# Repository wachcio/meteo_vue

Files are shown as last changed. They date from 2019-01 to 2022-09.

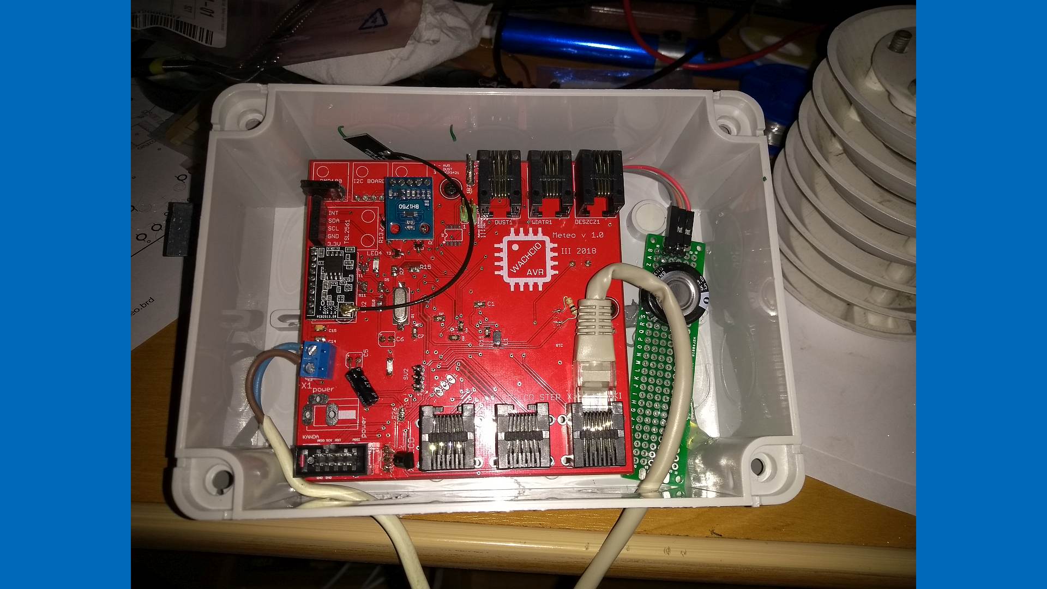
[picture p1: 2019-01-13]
src/assets/slider/IMG_20180407_161515269.jpg

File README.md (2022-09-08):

# meteo_vue
System zbierania danych z kilkudziesięciu czujników. Zaczął powstawać w maju 2016 roku. Strona typu SPA powstaje od grudnia 2018 przy pomocy framework-a Vue.

Od jakiegoś czasu działał u mnie minikomputer Raspberry Pi z zainstalowanym Raspianem oraz systemem monitoringu temperatury (i nie tylko) Nettemp autorstwa techfreak. Mierzy on temperatury w kotłowni i na zewnątrz budynku za pomocą czujników DS18B20 oraz DHT22 (bardzo słabe i zawodne).

Po kilku miesiącach zacząłem myśleć nad własną stacją pogody która mogła by oprócz temperatur mierzyłć również inne parametry i co najważniejsze była mojego autorstwa. Dzięki pomocy ze strony forum Atnel oraz kanałowi YouTube Atnel - mirekk36 zaprojektowałem a następnie polutowałem urządzenie i zaprogramowałem w języku C mikrokontroler Atmega 32A który jest sercem stacji meteo. Stacja zbiera informacje z czujników: temperatury (DS18B20, BMP180, SHT21), wilgotności (SHT21), ciśnienia (BMP180), wiatru, opadów oraz nasłonecznienia (BH1750). 9 lutego 2020 zamieniłem czujnki SHT21 i BMP 180 na jeden BME280 który mierzy temperaturę, ciśnienie i wilgotność.

Zachęcony udaną budową stacji złożyłem projekt firmy Atnel opisany w żółtej książce Mirosława Kardasia czyli zegar w dwóch sztukach. Po modyfikacjach oprogramowania zegary znajdujące się w salonie oraz sypialni wysyłają dane do Raspberry Pi który zapisuje je w zewnętrznej bazie danych.

Kolejną małą częścią projektu stało się urządzenie oparte o znany moduł wi-fi ESP8266 do którego podłączyłem czujnik temperatury DS18B20 w hermetcznej obudowie i umieściłem w akwarium. On również wysyła swoje dane do Nettemp-a.

Ostatnim elementem układanki jest odpytywanie bazy danych Airly o dane z czujników jakości powietrza znajdującego się w mojej miejscowości (od maja 2021 dostępne są dwa czujniki).

Dane z wszystkich moich części systemu trafiają co minutę (dane jakości powietrza ze względu na ograniczenia AirlyAPI odczytywane są co kwadrans) do bazy danych MySQL umieszczonej na zewnętrznym serwerze. Odbywa się to za pośrednictwem napisanych przeze mnie skryptów PHP. Dopiero z tej bazy poprzez mój mini system Rest API czerpie informacje ta strona. Jeśli jest problem z danym czujnikiem i z jakiegoś powodu dane są starsze niż 5 minut (16 minut czujniki jakości powietrza) sygnalizowane to jest czerwoną obwódką wokół ikony czujnika. Po kliknięciu na czujnik pokazują się bardziej szczegółowe informacje. Natomist kliknięcie na tytuł kategorii powoduje jej ukrycie lub pokazanie.

## Demo
http://meteo.wachcio.pl/

## Project setup
```
npm install
```

### Compiles and hot-reloads for development
```
npm run serve
```

### Compiles and minifies for production
```
npm run build
```

### Run your tests
```
npm run test
```

### Lints and fixes files
```
npm run lint
```

### Customize configuration
See [Configuration Reference](https://cli.vuejs.org/config/).

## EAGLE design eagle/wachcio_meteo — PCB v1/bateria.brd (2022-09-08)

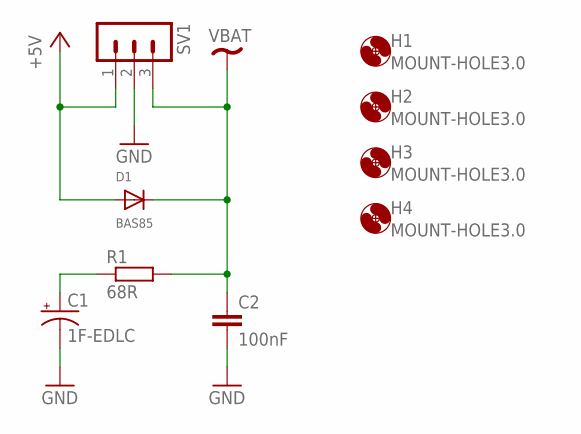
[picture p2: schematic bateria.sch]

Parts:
C1: 1F-EDLC; CAP-RADIAL-5MM-21.5MM
C2: 100nF; C0805
D1: BAS85; SMADIODE
H1, H2, H3, H4: MOUNT-HOLE3.0; 3,0
R1: 68R; R0805
SV1: MA03-1

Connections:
+5V: D1.A, SV1.1
GND: C1.-, C2.2, SV1.2
unnamed: C1.+, R1.1
VBAT: C2.1, D1.C, R1.2, SV1.3

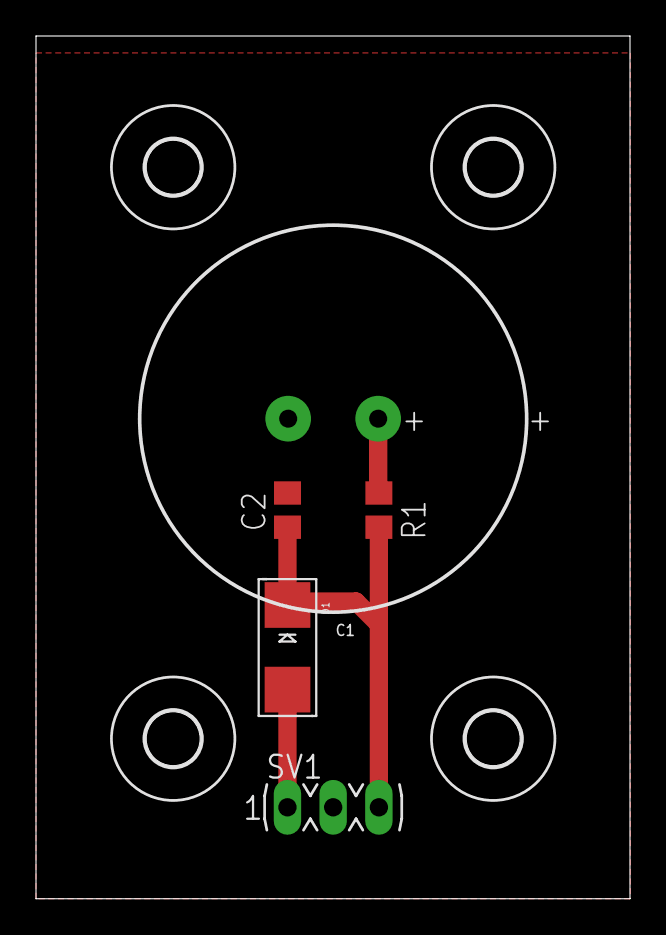
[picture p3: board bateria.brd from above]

Board: 2 copper layers, 33.0 x 47.9 mm, 9 parts (0 on the bottom side), 4 nets.

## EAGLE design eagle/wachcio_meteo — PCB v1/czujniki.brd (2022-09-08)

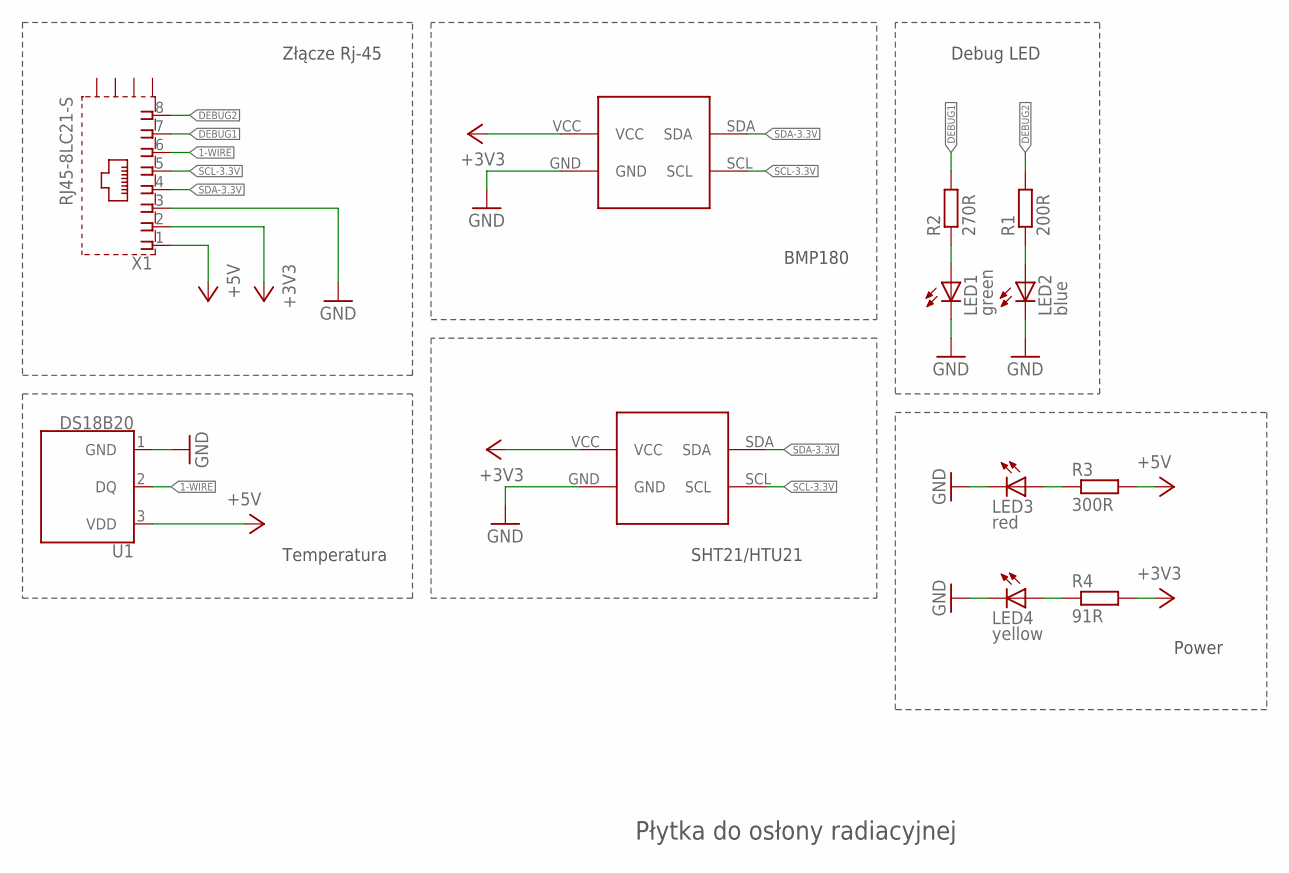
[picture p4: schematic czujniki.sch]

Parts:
LED1: green; CHIPLED_1206
LED2: blue; CHIPLED_1206
LED3: red; CHIPLED_1206
LED4: yellow; CHIPLED_1206
R1: 200R; M0805
R2: 270R; M0805
R3: 300R; M0805
R4: 91R; M0805
U1: DS18B20; TO-92-AMMO
U$1: BMP180
U$2: I2C_BOARD
X1: RJ45-8LC21-S; RJ45-SHIELD1

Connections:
1-WIRE: U1.2 (DQ), X1.6
+3V3: R4.2, U$1.VCC, U$2.VCC, X1.2
+5V: R3.2, U1.3 (VDD), X1.1
DEBUG1: R2.2, X1.7
DEBUG2: R1.2, X1.8
GND: LED1.C, LED2.C, LED3.C, LED4.C, U1.1 (GND), U$1.GND, U$2.GND, X1.3
unnamed: LED1.A, R2.1
unnamed: LED2.A, R1.1
unnamed: LED3.A, R3.1
unnamed: LED4.A, R4.1
SCL-3.3V: U$1.SCL, U$2.SCL, X1.5
SDA-3.3V: U$1.SDA, U$2.SDA, X1.4

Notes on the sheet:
BMP180
SHT21/HTU21
Złącze Rj-45
Temperatura
Debug LED
Płytka do osłony radiacyjnej
Power

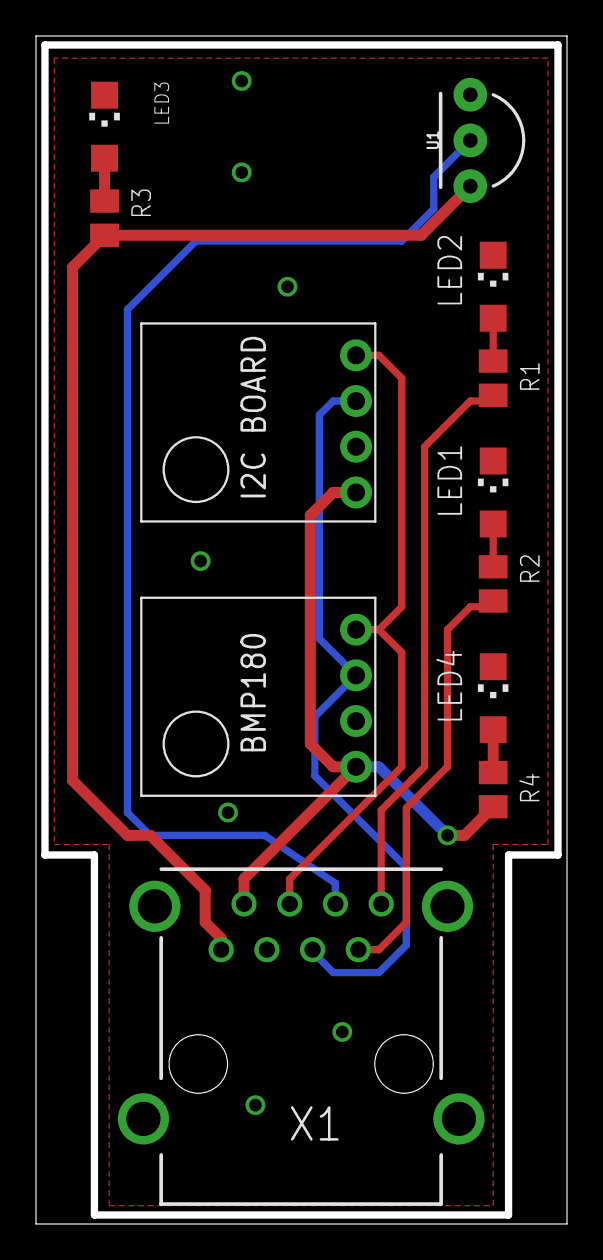
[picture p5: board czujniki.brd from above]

Board: 2 copper layers, 29.5 x 66.0 mm, 12 parts (0 on the bottom side), 12 nets.

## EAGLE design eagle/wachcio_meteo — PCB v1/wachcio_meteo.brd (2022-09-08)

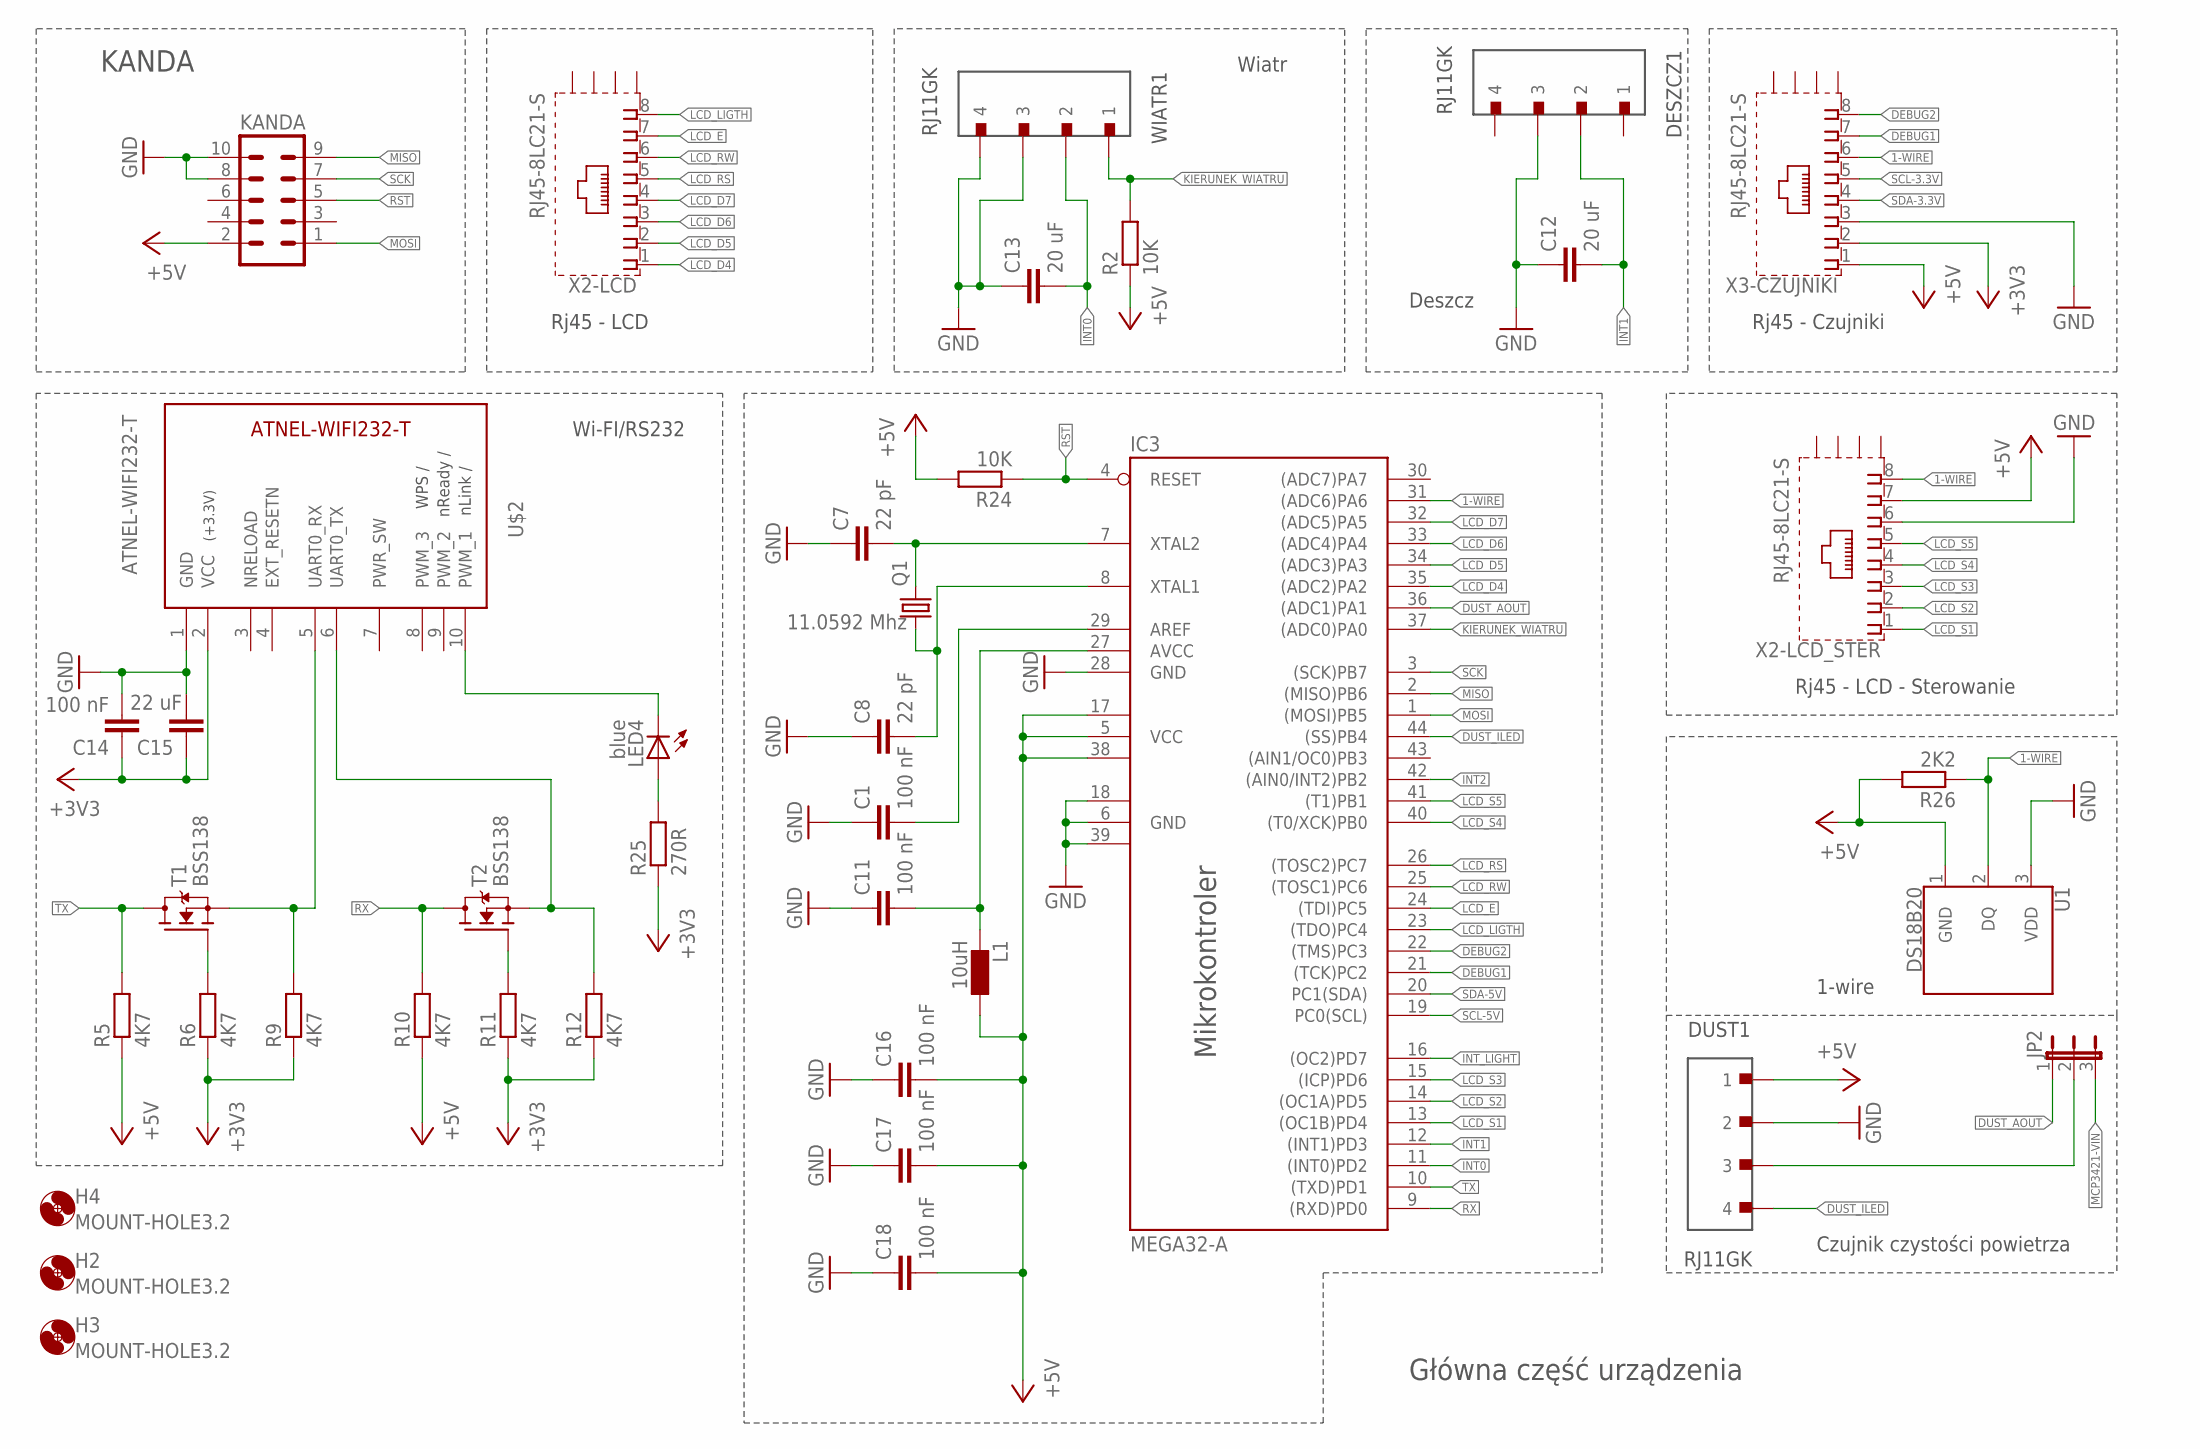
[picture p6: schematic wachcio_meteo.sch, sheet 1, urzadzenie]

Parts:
C1, C11, C14, C16, C17, C18: 100 nF; C0805
C7, C8: 22 pF; C0805
C12, C13: 20 uF; C0805
C15: 22 uF; C0805
DESZCZ1: RJ11GK
DUST1: RJ11GK
H2, H3, H4: MOUNT-HOLE3.2; 3,2
IC3: MEGA32-A; TQFP44
JP2: JP2E; JP2
KANDA: ML10
L1: 10uH; L3230M
LED4: blue; CHIPLED_1206
Q1: 11.0592 Mhz; SM49
R2, R24: 10K; M0805
R5, R6, R9, R10, R11, R12: 4K7; M0805
R25: 270R; M0805
R26: 2K2; M0805
T1, T2: BSS138; SOT23
U1: DS18B20; TO-92-AMMO
U$2: ATNEL-WIFI232-T
WIATR1: RJ11GK
X2-LCD, X2-LCD_STER, X3-CZUJNIKI: RJ45-8LC21-S; RJ45-SHIELD1

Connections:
1-WIRE: IC3.31 ((ADC6)PA6), R26.1, U1.2 (DQ), X2-LCD_STER.8, X3-CZUJNIKI.6
+3V3: C14.1, C15.1, R6.1, R9.1, R11.1, R12.1, R25.1, U$2.2 (VCC), X3-CZUJNIKI.2; also elsewhere on the board
+5V: C16.2, C17.2, C18.2, DUST1.1, IC3.5 (VCC), IC3.17 (VCC1), IC3.38 (VCC2), KANDA.2, L1.1, R2.1, R5.1, R10.1, R24.2, R26.2, U1.1 (GND), X2-LCD_STER.7, X3-CZUJNIKI.1; also elsewhere on the board
DEBUG1: IC3.21 ((TCK)PC2), X3-CZUJNIKI.7
DEBUG2: IC3.22 ((TMS)PC3), X3-CZUJNIKI.8
DUST_AOUT: IC3.36 ((ADC1)PA1), JP2.1
DUST_ILED: DUST1.4, IC3.44 ((SS)PB4)
GND: C1.1, C7.1, C8.1, C11.1, C12.1, C13.1, C14.2, C15.2, C16.1, C17.1, C18.1, DESZCZ1.3, DUST1.2, IC3.6 (GND), IC3.18 (GND1), IC3.28 (GND), IC3.39 (GND2), KANDA.8, KANDA.10, U1.3 (VDD), U$2.1 (GND), WIATR1.3, WIATR1.4, X2-LCD_STER.6, X3-CZUJNIKI.3; also elsewhere on the board
INT0: C13.2, IC3.11 ((INT0)PD2), WIATR1.2
INT1: C12.2, DESZCZ1.2, IC3.12 ((INT1)PD3)
INT2: IC3.42 ((AIN0/INT2)PB2); also elsewhere on the board
INT_LIGHT: IC3.16 ((OC2)PD7); also elsewhere on the board
KIERUNEK_WIATRU: IC3.37 ((ADC0)PA0), R2.2, WIATR1.1
LCD_D4: IC3.35 ((ADC2)PA2), X2-LCD.1
LCD_D5: IC3.34 ((ADC3)PA3), X2-LCD.2
LCD_D6: IC3.33 ((ADC4)PA4), X2-LCD.3
LCD_D7: IC3.32 ((ADC5)PA5), X2-LCD.4
LCD_E: IC3.24 ((TDI)PC5), X2-LCD.7
LCD_LIGTH: IC3.23 ((TDO)PC4), X2-LCD.8
LCD_RS: IC3.26 ((TOSC2)PC7), X2-LCD.5
LCD_RW: IC3.25 ((TOSC1)PC6), X2-LCD.6
LCD_S1: IC3.13 ((OC1B)PD4), X2-LCD_STER.1
LCD_S2: IC3.14 ((OC1A)PD5), X2-LCD_STER.2
LCD_S3: IC3.15 ((ICP)PD6), X2-LCD_STER.3
LCD_S4: IC3.40 ((T0/XCK)PB0), X2-LCD_STER.4
LCD_S5: IC3.41 ((T1)PB1), X2-LCD_STER.5
MCP3421-VIN: JP2.3; also elsewhere on the board
MISO: IC3.2 ((MISO)PB6), KANDA.9
MOSI: IC3.1 ((MOSI)PB5), KANDA.1
unnamed: R9.2, T1.2 (S), U$2.5 (UART0_RX)
unnamed: C11.2, IC3.27 (AVCC), L1.2
unnamed: C1.2, IC3.29 (AREF)
unnamed: LED4.A, R25.2
unnamed: R6.2, T1.1 (G)
unnamed: LED4.C, U$2.10 (PWM_1)
unnamed: R12.2, T2.2 (S), U$2.6 (UART0_TX)
unnamed: C7.2, IC3.7 (XTAL2), Q1.2
unnamed: C8.2, IC3.8 (XTAL1), Q1.1
unnamed: DUST1.3, JP2.2
unnamed: R11.2, T2.1 (G)
RST: IC3.4 (RESET), KANDA.5, R24.1
RX: IC3.9 ((RXD)PD0), R10.2, T2.3 (D)
SCK: IC3.3 ((SCK)PB7), KANDA.7
SCL-3.3V: X3-CZUJNIKI.5; also elsewhere on the board
SCL-5V: IC3.19 (PC0(SCL)); also elsewhere on the board
SDA-3.3V: X3-CZUJNIKI.4; also elsewhere on the board
SDA-5V: IC3.20 (PC1(SDA)); also elsewhere on the board
TX: IC3.10 ((TXD)PD1), R5.2, T1.3 (D)

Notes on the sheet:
KANDA
Mikrokontroler
Rj45 - LCD
Wiatr
Deszcz
Rj45 - Czujniki
Wi-FI/RS232
1-wire
Rj45 - LCD - Sterowanie
Główna część urządzenia
Czujnik czystości powietrza

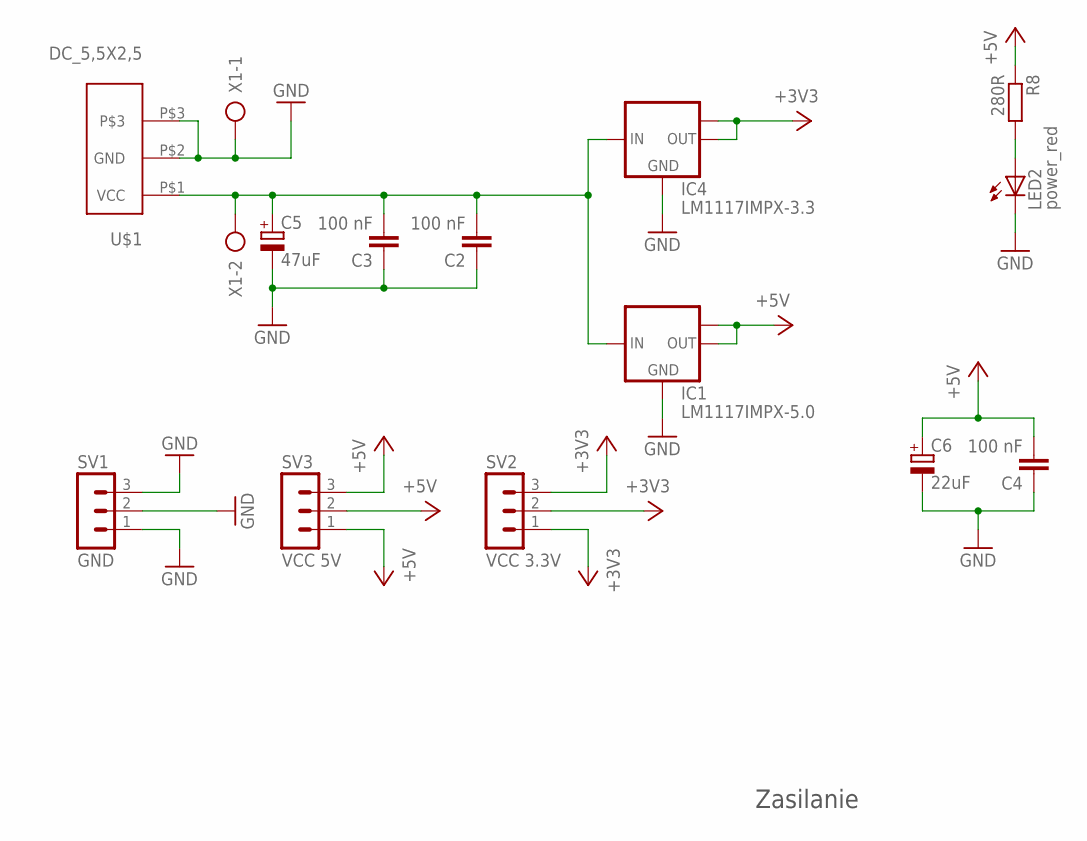
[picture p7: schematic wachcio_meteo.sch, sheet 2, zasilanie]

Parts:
C2, C3, C4: 100 nF; C0805
C5: 47uF; B45181A
C6: 22uF; B45181A
IC1: LM1117IMPX-5.0; SOT223
IC4: LM1117IMPX-3.3; SOT223
LED2: power_red; CHIPLED_1206
R8: 280R; M0805
SV1: GND; MA03-1
SV2: VCC 3.3V; MA03-1
SV3: VCC 5V; MA03-1
U$1: DC_5,5X2,5
X1: AK500/2

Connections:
+3V3: IC4.2 (OUT), IC4.TAB (OUT1), SV2.1, SV2.2, SV2.3; also elsewhere on the board
+5V: C4.2, C6.+, IC1.2 (OUT), IC1.TAB (OUT1), R8.1, SV3.1, SV3.2, SV3.3; also elsewhere on the board
+9V: C2.2, C3.2, C5.+, IC1.3 (IN), IC4.3 (IN), U$1.P$1 (VCC), X1.2
GND: C2.1, C3.1, C4.1, C5.-, C6.-, IC1.1 (GND), IC4.1 (GND), LED2.C, SV1.1, SV1.2, SV1.3, U$1.P$2 (GND), U$1.P$3, X1.1; also elsewhere on the board
unnamed: LED2.A, R8.2

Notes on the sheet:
Zasilanie

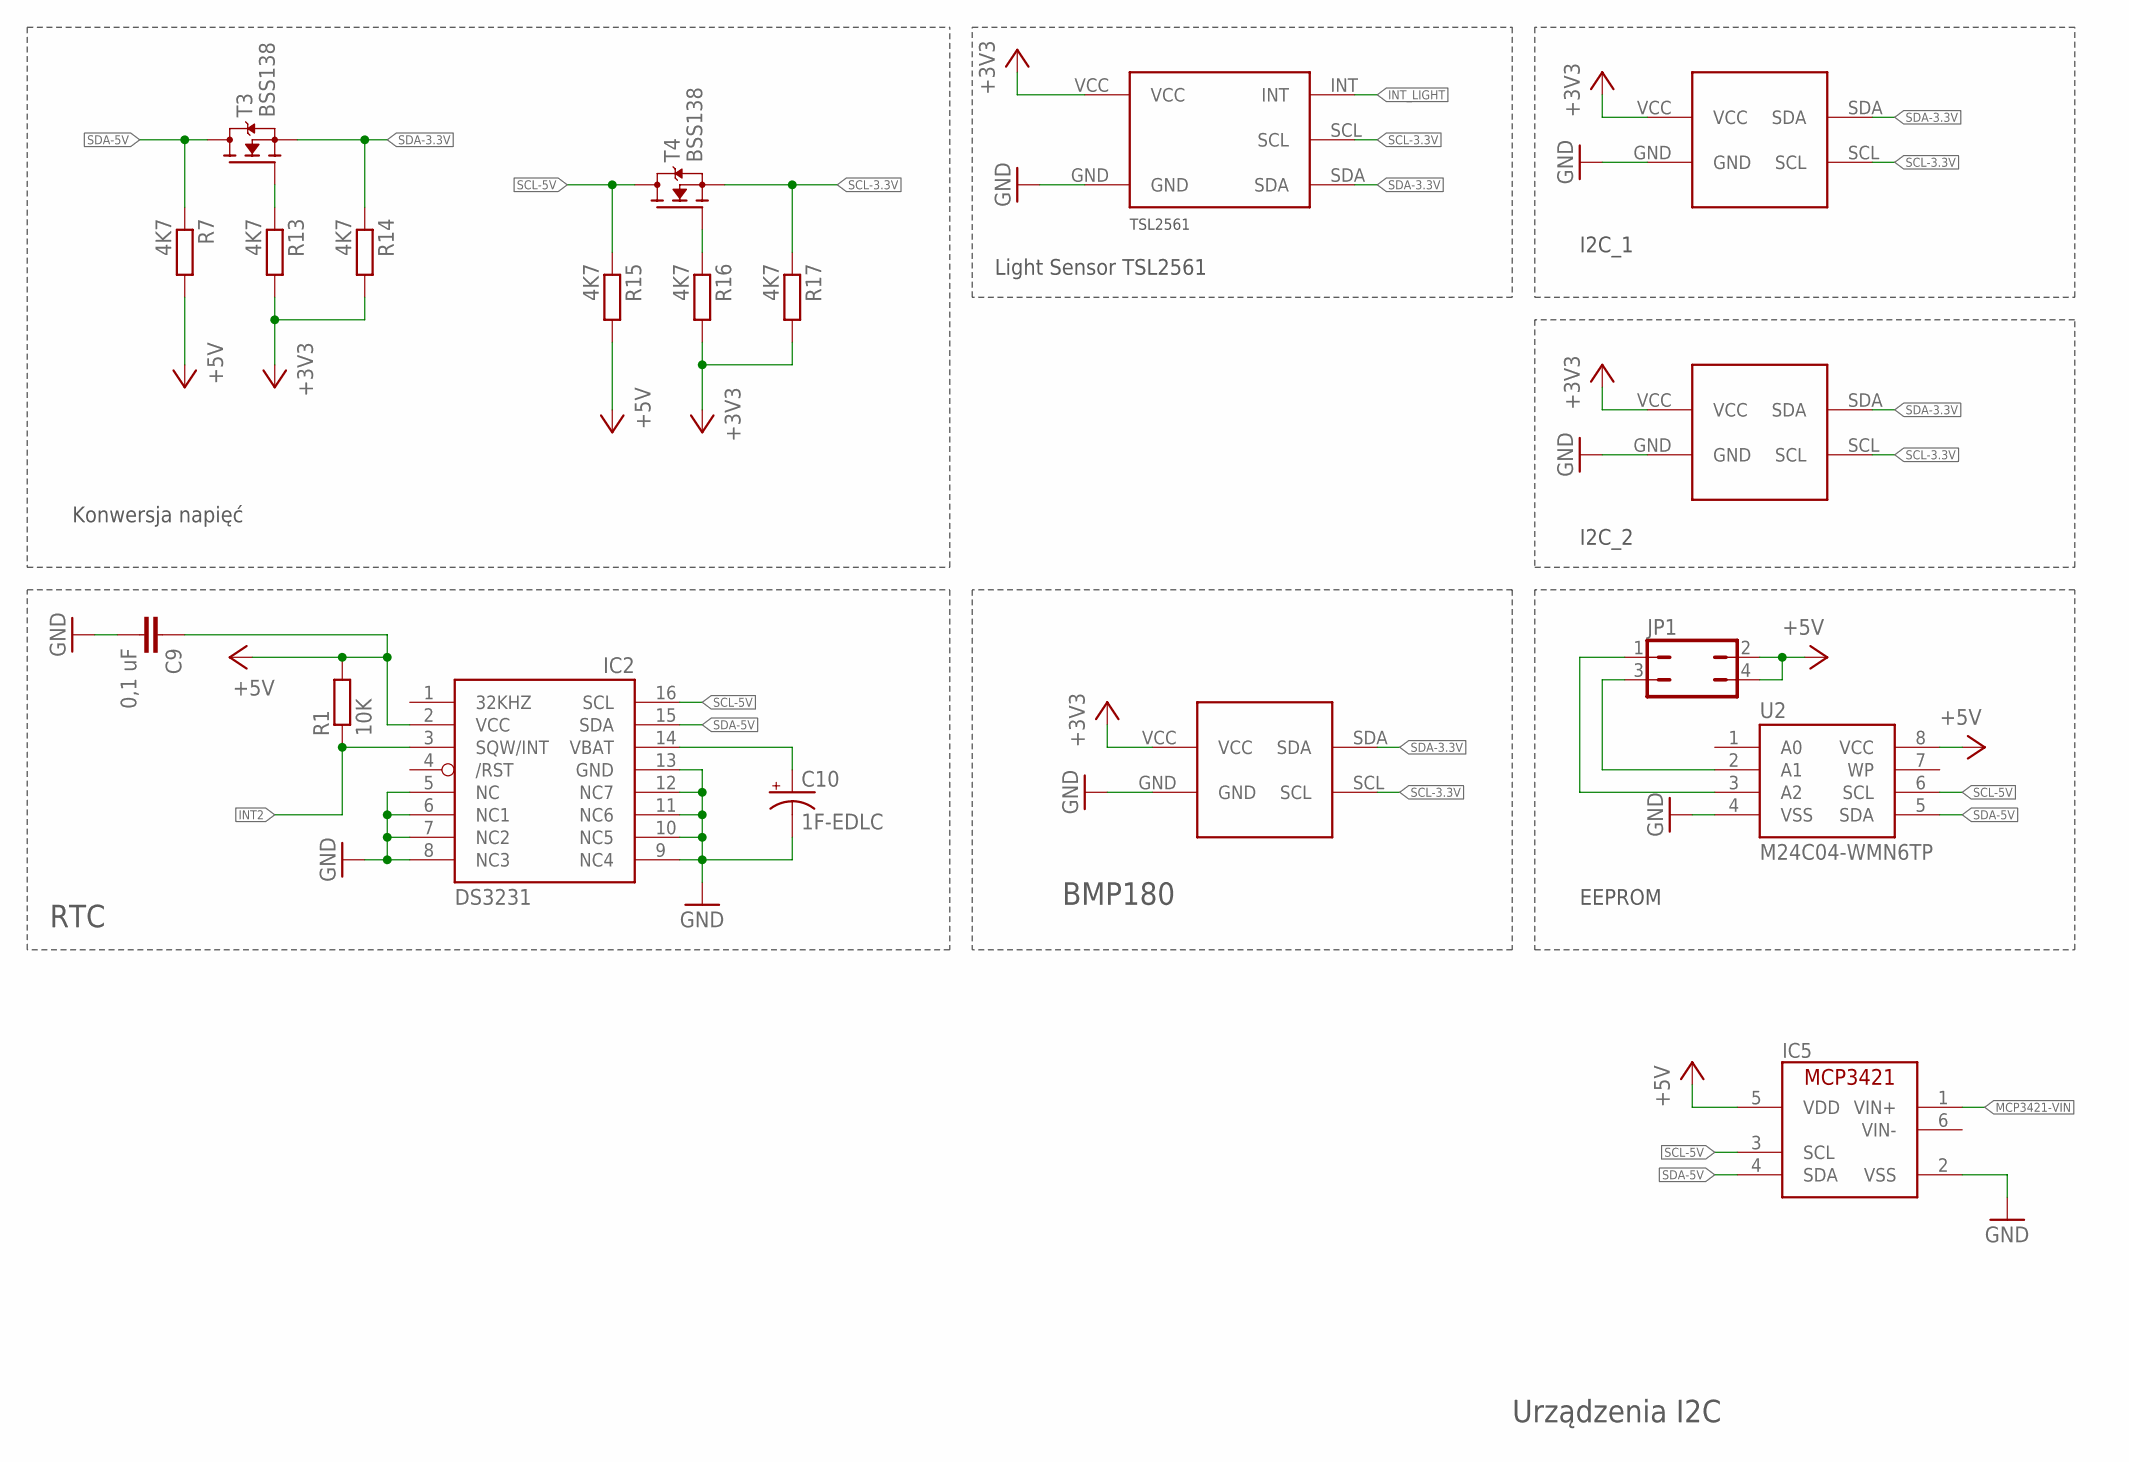
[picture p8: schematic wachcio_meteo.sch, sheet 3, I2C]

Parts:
C9: 0,1 uF; C0805
C10: 1F-EDLC; CAP-RADIAL-5MM-21.5MM
IC2: DS3231/SO; SO16W
IC5: MCP3421; SOT-23
JP1: JP2Q
R1: 10K; M0805
R7, R13, R14, R15, R16, R17: 4K7; M0805
T3, T4: BSS138; SOT23
U2: M24C04-WMN6TP; SO08
U$3: BMP180
U$5, U$6: I2C_BOARD
U$7: TSL2561GY-2561; TSL2561

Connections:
+3V3: R13.2, R14.2, R16.2, R17.2, U$3.VCC, U$5.VCC, U$6.VCC, U$7.VCC; also elsewhere on the board
+5V: C9.1, IC2.2 (VCC), IC5.5 (VDD), JP1.2, JP1.4, R1.2, R7.2, R15.2, U2.8 (VCC); also elsewhere on the board
GND: C9.2, C10.-, IC2.5 (NC), IC2.6 (NC1), IC2.7 (NC2), IC2.8 (NC3), IC2.9 (NC4), IC2.10 (NC5), IC2.11 (NC6), IC2.12 (NC7), IC2.13 (GND), IC5.2 (VSS), U2.4 (VSS), U$3.GND, U$5.GND, U$6.GND, U$7.GND; also elsewhere on the board
INT2: IC2.3 (SQW/INT), R1.1; also elsewhere on the board
INT_LIGHT: U$7.INT; also elsewhere on the board
MCP3421-VIN: IC5.1 (VIN+); also elsewhere on the board
unnamed: C10.+, IC2.14 (VBAT)
unnamed: R13.1, T3.1 (G)
unnamed: R16.1, T4.1 (G)
unnamed: JP1.3, U2.2 (A1)
unnamed: JP1.1, U2.3 (A2)
SCL-3.3V: R17.1, T4.2 (S), U$3.SCL, U$5.SCL, U$6.SCL, U$7.SCL; also elsewhere on the board
SCL-5V: IC2.16 (SCL), IC5.3 (SCL), R15.1, T4.3 (D), U2.6 (SCL); also elsewhere on the board
SDA-3.3V: R14.1, T3.2 (S), U$3.SDA, U$5.SDA, U$6.SDA, U$7.SDA; also elsewhere on the board
SDA-5V: IC2.15 (SDA), IC5.4 (SDA), R7.1, T3.3 (D), U2.5 (SDA); also elsewhere on the board

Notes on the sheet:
Konwersja napięć
RTC
BMP180
I2C_1
I2C_2
EEPROM
Light Sensor TSL2561
Urządzenia I2C

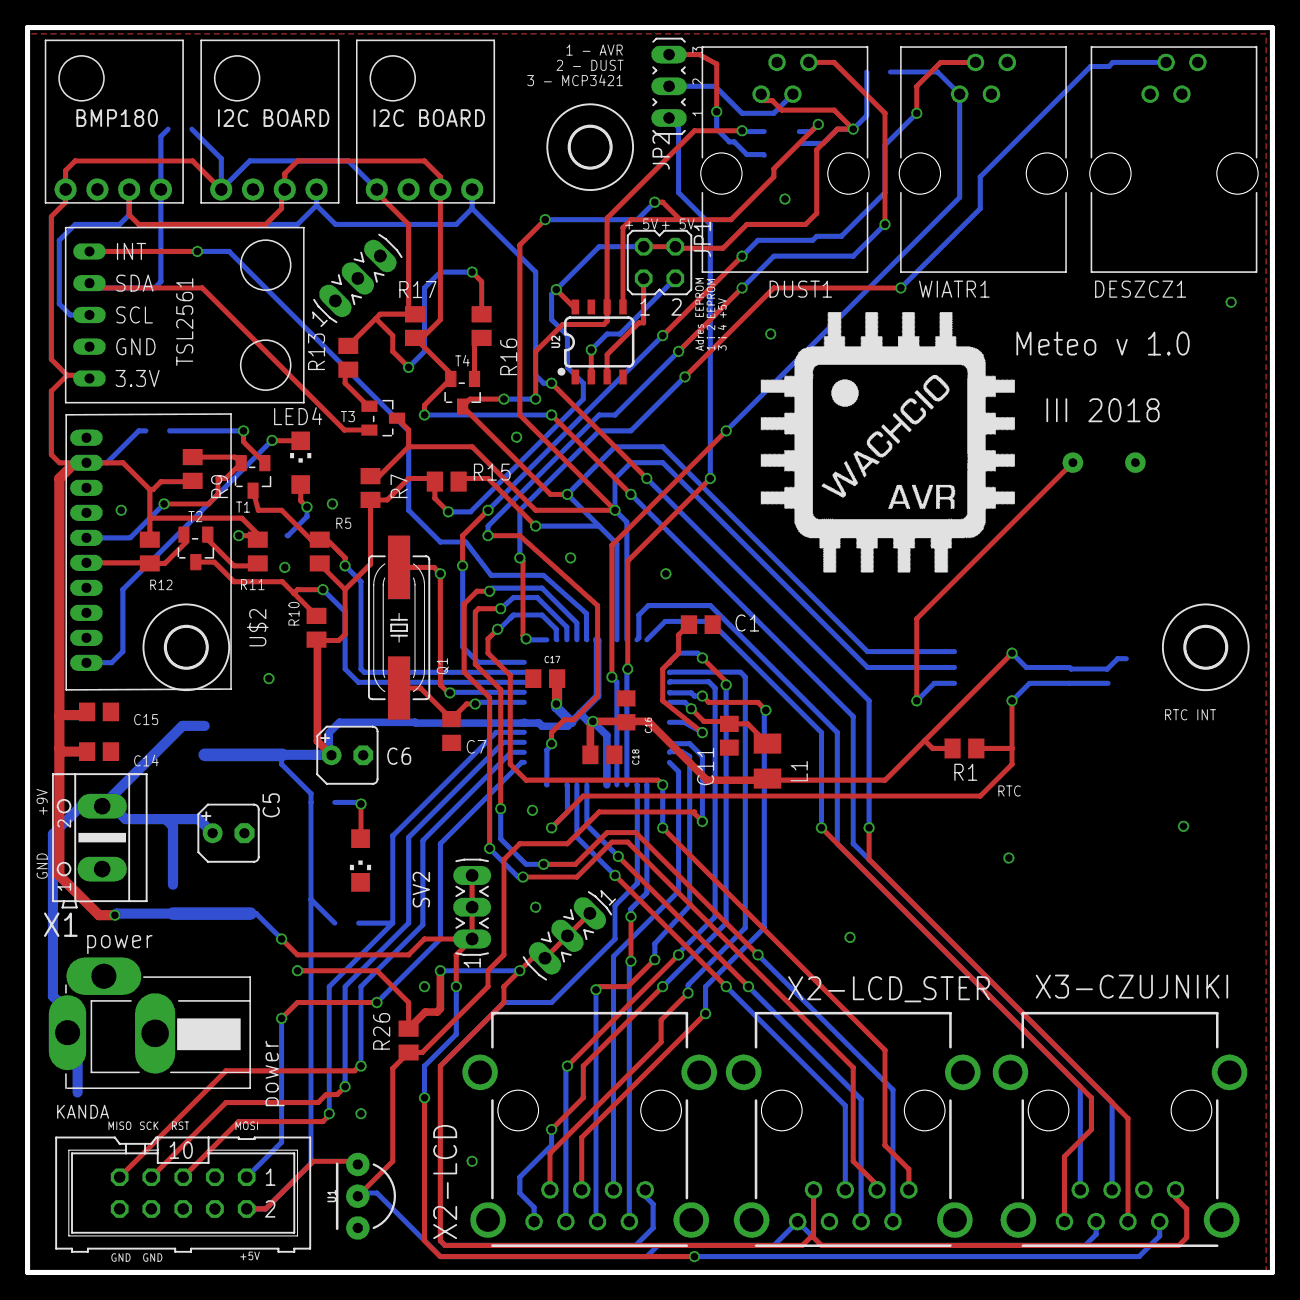
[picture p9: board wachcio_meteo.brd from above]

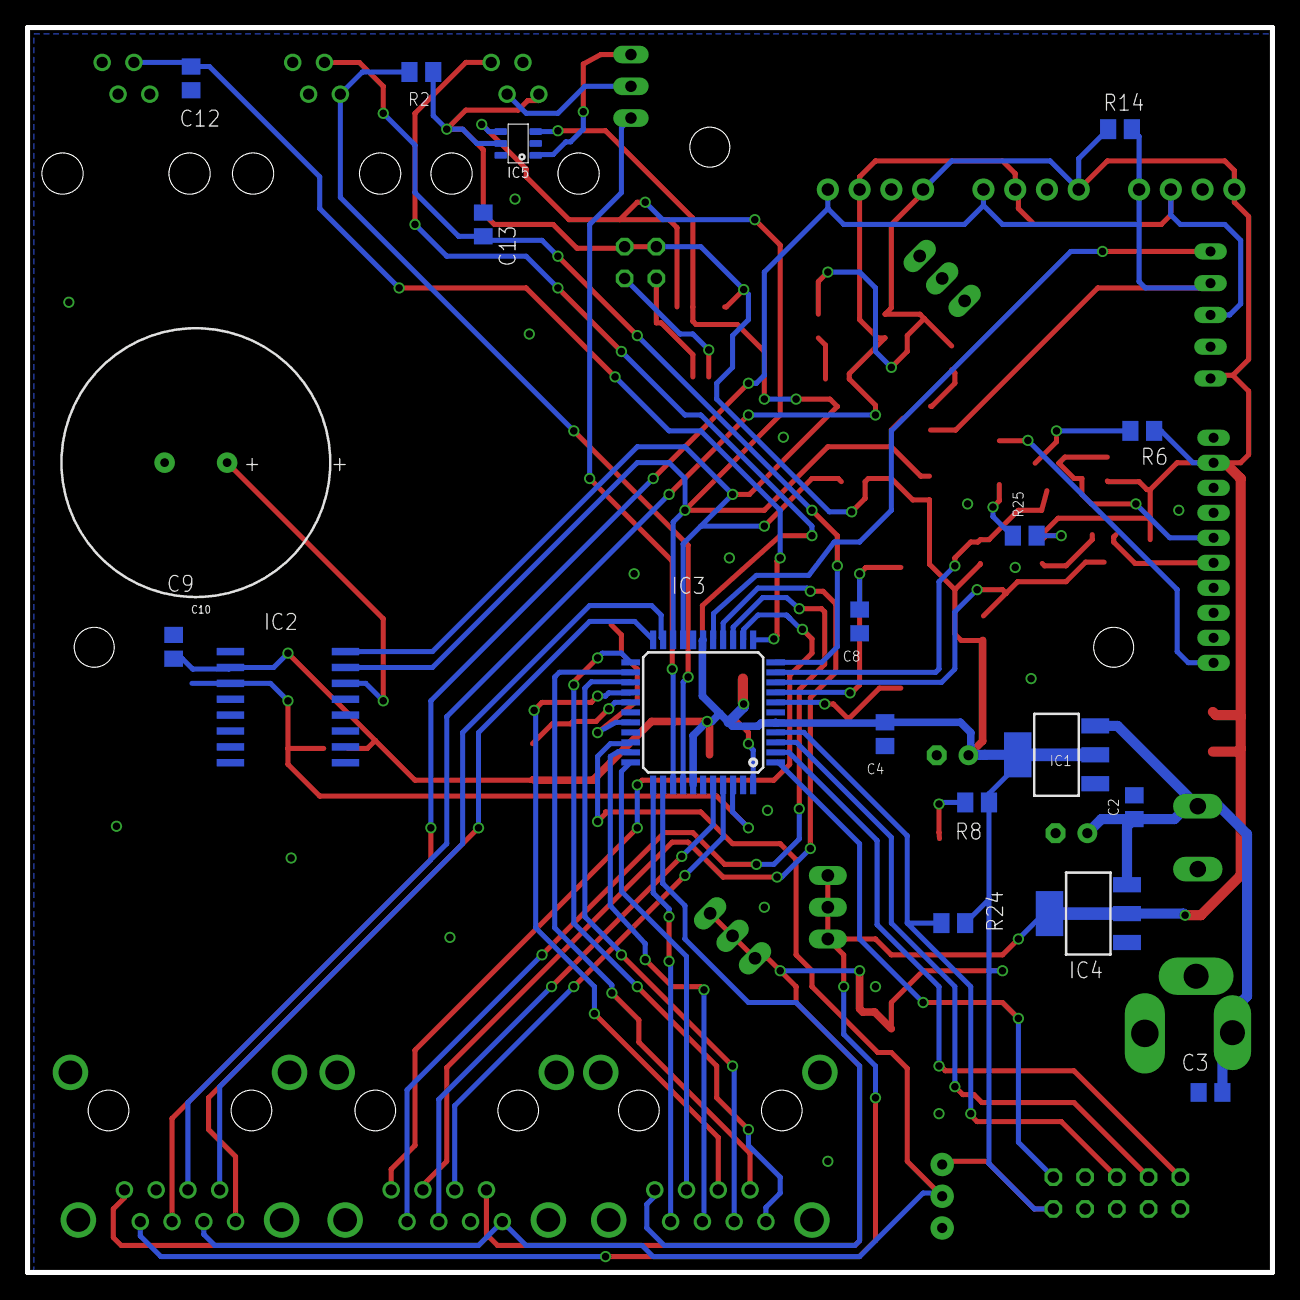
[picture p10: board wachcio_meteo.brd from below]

Board: 2 copper layers, 99.6 x 99.6 mm, 74 parts (19 on the bottom side), 55 nets.

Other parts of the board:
U$8: LOGO

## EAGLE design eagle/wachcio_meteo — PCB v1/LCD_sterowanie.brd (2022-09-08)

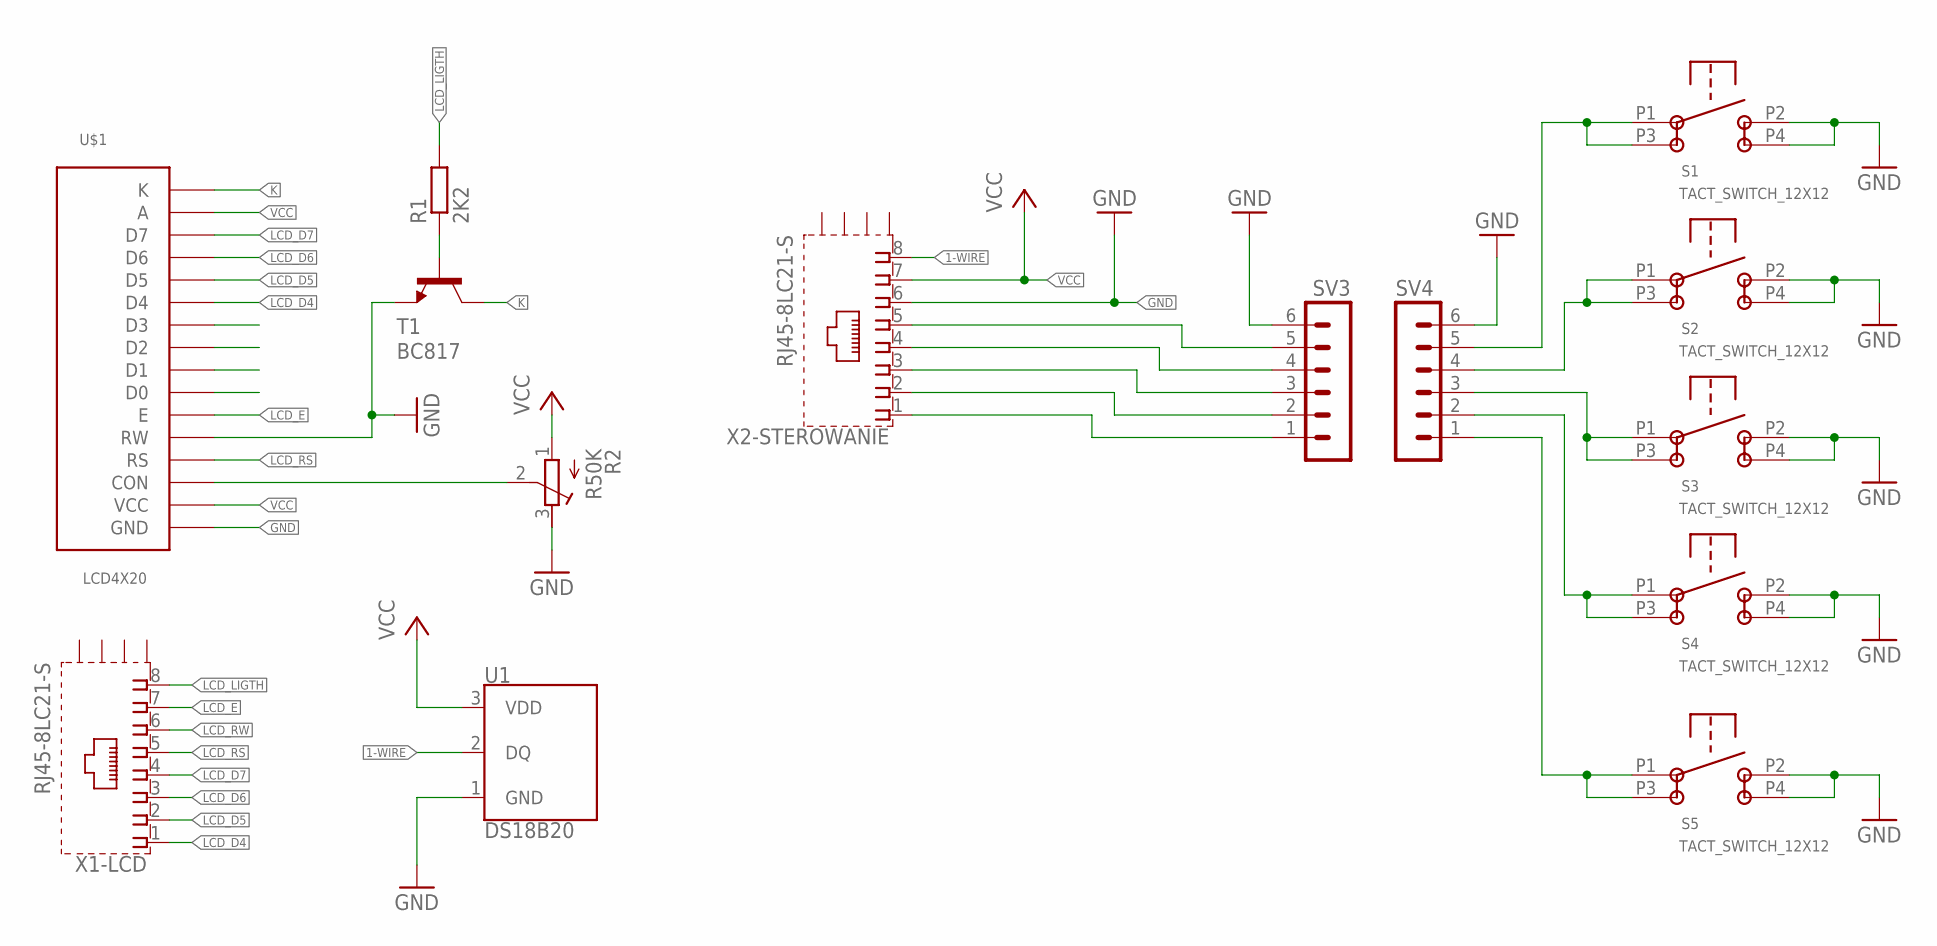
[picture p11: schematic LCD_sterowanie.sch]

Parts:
R1: 2K2; M0805
R2: R50K; RTRIM3296P
S1, S2, S3, S4, S5: TACT_SWITCH_12X12
SV3, SV4: MA06-1
T1: BC817; SOT23
U1: DS18B20; TO-92-AMMO
U$1: LCD4X20
X1-LCD, X2-STEROWANIE: RJ45-8LC21-S; RJ45-SHIELD1

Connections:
1-WIRE: U1.2 (DQ), X2-STEROWANIE.8
GND: R2.3 (E), S1.P2, S1.P4, S2.P2, S2.P4, S3.P2, S3.P4, S4.P2, S4.P4, S5.P2, S5.P4, SV3.6, SV4.6, T1.2 (E), U1.1 (GND), U$1.GND, U$1.RW, X2-STEROWANIE.6
K: T1.3 (C), U$1.K
LCD_D4: U$1.D4, X1-LCD.1
LCD_D5: U$1.D5, X1-LCD.2
LCD_D6: U$1.D6, X1-LCD.3
LCD_D7: U$1.D7, X1-LCD.4
LCD_E: U$1.E, X1-LCD.7
LCD_LIGTH: R1.2, X1-LCD.8
LCD_RS: U$1.RS, X1-LCD.5
LCD_RW: X1-LCD.6
unnamed: R1.1, T1.1 (B)
unnamed: S1.P1, S1.P3, SV4.5
unnamed: S2.P1, S2.P3, SV4.4
unnamed: S3.P1, S3.P3, SV4.3
unnamed: S4.P1, S4.P3, SV4.2
unnamed: S5.P1, S5.P3, SV4.1
unnamed: R2.2 (S), U$1.CON
S1: SV3.1, X2-STEROWANIE.1
S2: SV3.2, X2-STEROWANIE.2
S3: SV3.3, X2-STEROWANIE.3
S4: SV3.4, X2-STEROWANIE.4
S5: SV3.5, X2-STEROWANIE.5
VCC: R2.1 (A), U1.3 (VDD), U$1.A, U$1.VCC, X2-STEROWANIE.7

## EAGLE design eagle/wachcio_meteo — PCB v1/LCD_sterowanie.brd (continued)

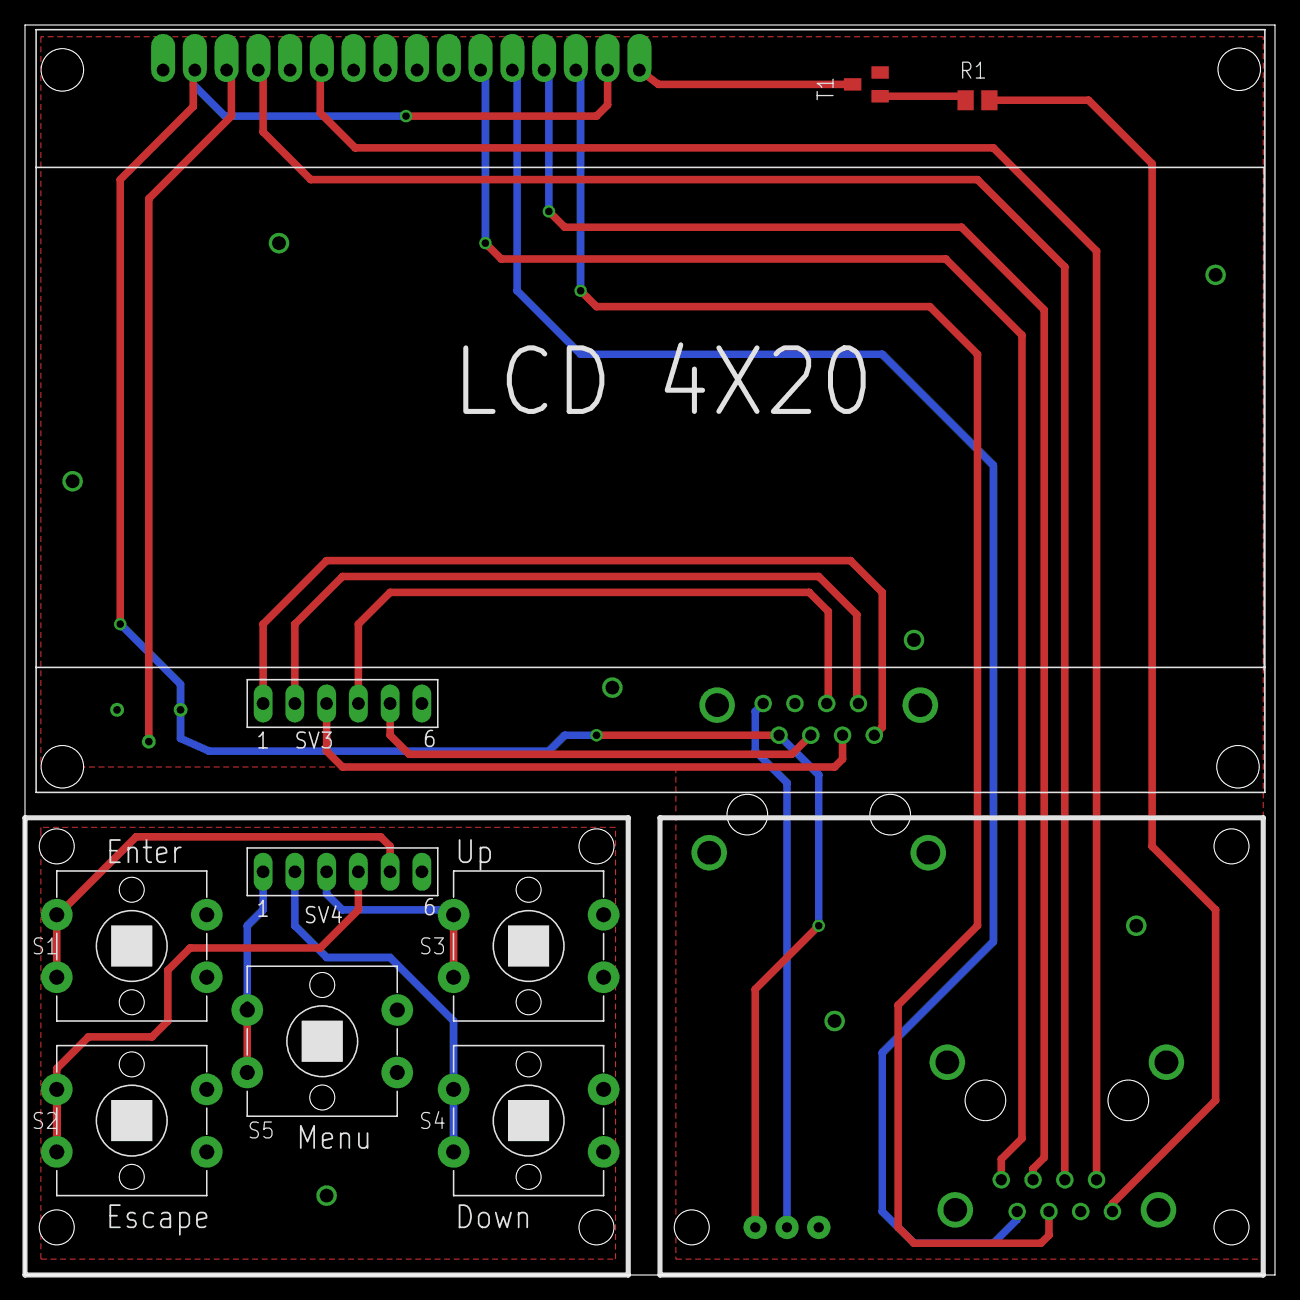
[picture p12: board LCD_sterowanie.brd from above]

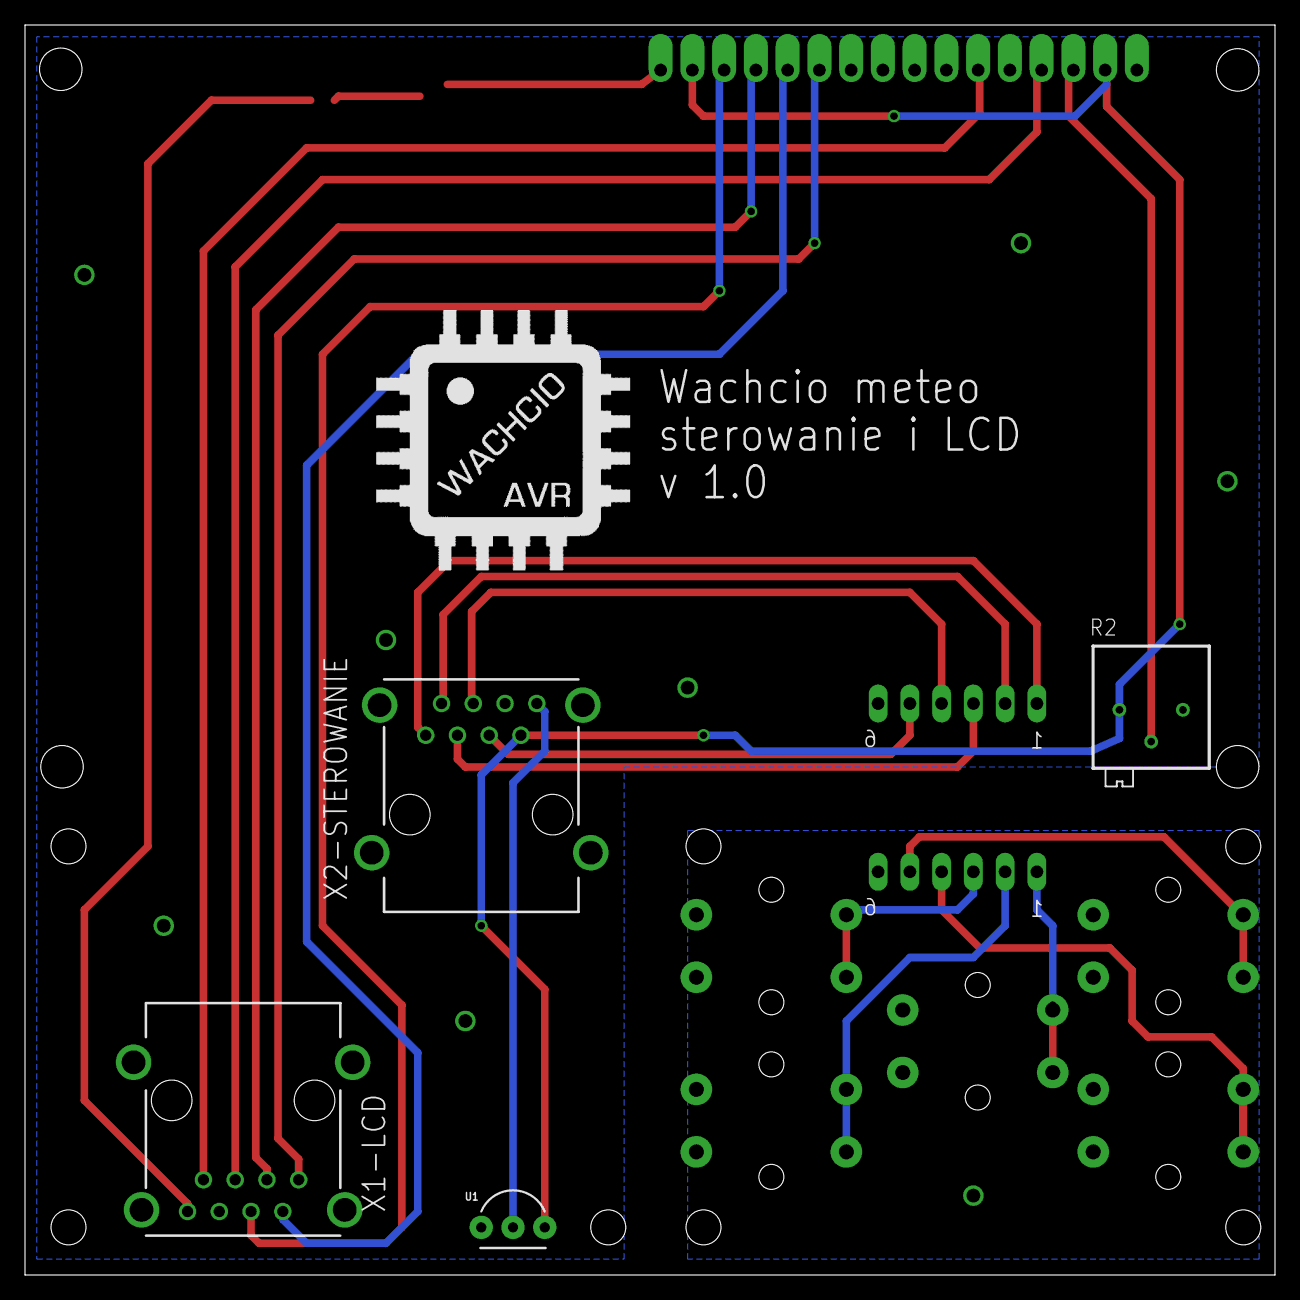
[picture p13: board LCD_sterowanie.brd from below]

Board: 2 copper layers, 100.0 x 100.0 mm, 15 parts (5 on the bottom side), 23 nets.

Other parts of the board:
U$2: LOGO

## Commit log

2018-12-08 Create Sensor component
2018-12-09 Cleaning component Sensor
2018-12-09 Add SensorCategory
2018-12-09 Fixed css to SensorCatagory
2018-12-09 Fixed value of sensor
2018-12-13 Hide nav buttons
2018-12-13 Active buttons in nav
2018-12-15 Ficed bug whit opady and kierunek wiatru sensor
2018-12-17 Add 'bezwietrznie' state in wind direction sensor
2018-12-22 Fixed problem whit show/hide sensor category
2018-12-23 When wind Speed is 0 then change sensor picture and value
2018-12-31 Fixed show current sensors on load
2019-01-04 Add alarm min and max to table sensors
2019-01-04 Split sensors.php
2019-01-13 CSS change and add upToDate sensor in JSON
2022-09-08 Add files via upload
    Add files Eagle PCB project
    [LCD_sterowanie.brd, LCD_sterowanie.sch, bateria.brd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]

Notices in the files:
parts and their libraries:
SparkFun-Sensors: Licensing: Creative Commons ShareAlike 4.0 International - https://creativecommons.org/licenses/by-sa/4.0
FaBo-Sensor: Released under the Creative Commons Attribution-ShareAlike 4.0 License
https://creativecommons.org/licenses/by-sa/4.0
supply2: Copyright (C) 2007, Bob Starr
